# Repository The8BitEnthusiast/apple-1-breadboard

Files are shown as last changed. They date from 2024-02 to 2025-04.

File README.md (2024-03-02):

# Apple 1 Computer on Breadboard

Splash

This is an implementation of the Apple 1 computer on breadboard with the help of FPGA to support video display and PS/2 to ASCII keyboard conversion.

## Design Overview

This project builds upon Ben Eater's [6502 computer project](https://eater.net/6502). The base configuration of the WDC 65C02 microprocessor, 62256 RAM chip and 28C256 EEPROM is the same. Modifications made to the design to bring it into full compatibility with the Apple 1 are as follows:

- An FPGA is used to emulate the Apple 1 Video Terminal circuit and also to allow the use of a standard PS/2 keyboard by converting the PS/2 protocol to the ASCII signals expected by the Apple 1. The Video Terminal is the result of another project of mine, the details of which can be found [here](https://github.com/The8BitEnthusiast/apple-1-video-terminal-on-fpga).
- The 65C22 VIA IC is replaced with the 65C21 PIA, which is a drop-in replacement for the original PIA used on the Apple 1.
- Address decoding was adjusted to match the Apple 1's memory map. Worth noting is that the EEPROM is selected for the $F000-$FFFF address range, which was used to hold Wozmon, and the $C000-$CFFF range, used for Apple 1 Cassette Interface. RAM is selected for the bottom half of the memory space, and also for the $E000-$EFFF, which was used to load BASIC. This creates a range conflict with $6000-$6FFF, but for the purpose of this project, that was OK.

The top level schematic of this design is shown below. The KiCAD files are available in the schematics folder of this project.

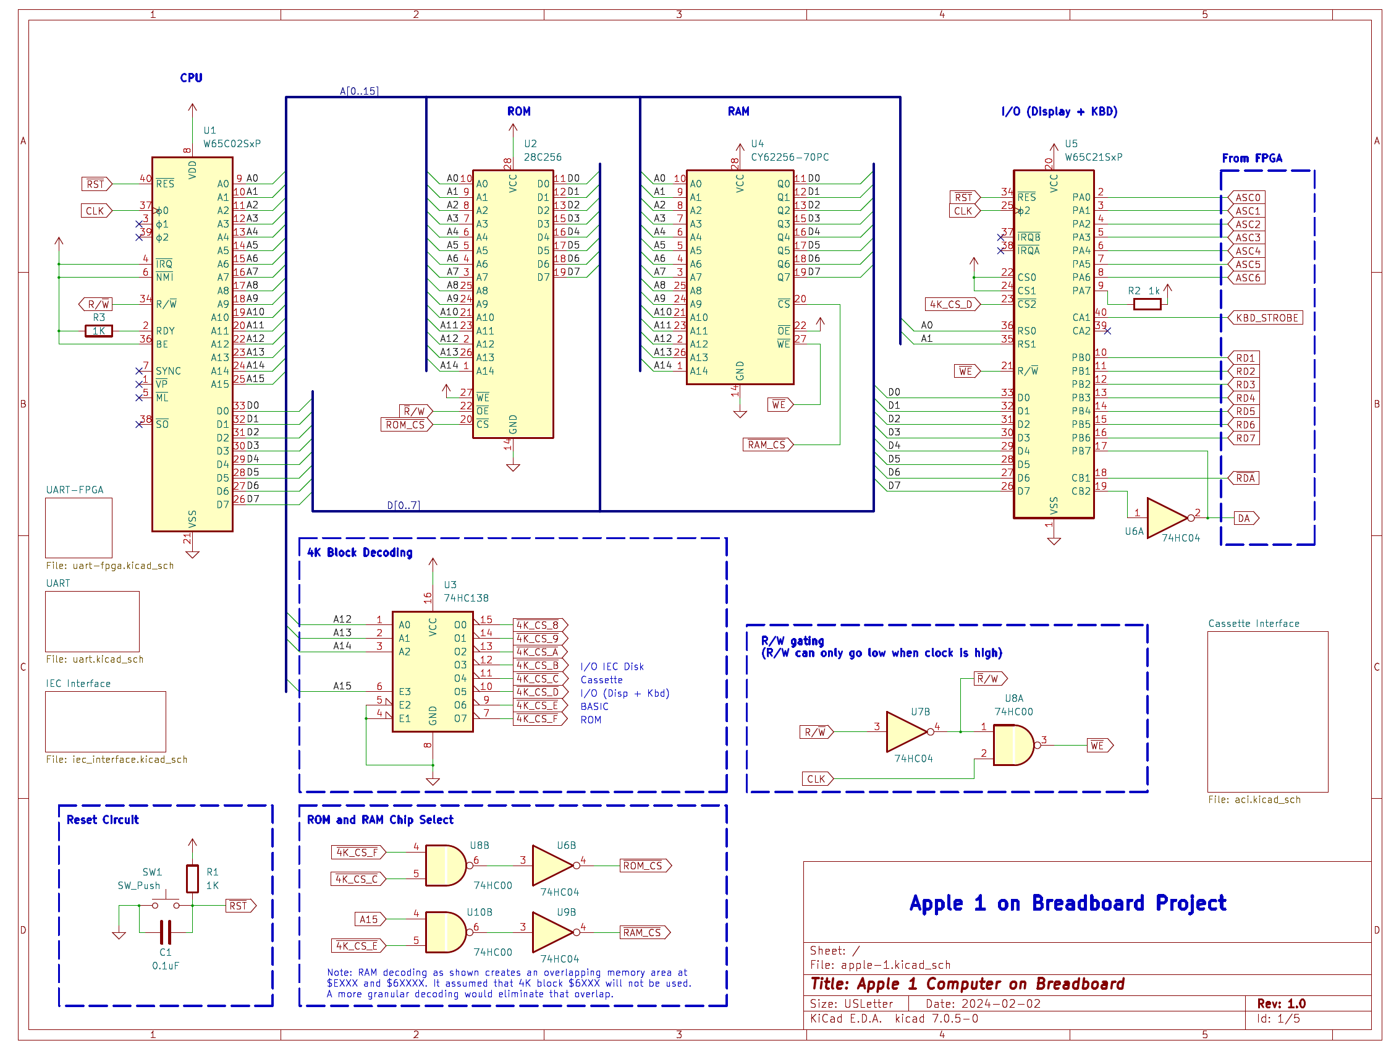
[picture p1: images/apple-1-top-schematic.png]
Top Schematic


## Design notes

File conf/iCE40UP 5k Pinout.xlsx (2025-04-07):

# Pin Out For iCE5UP5K (iCE40 UltraPlus - 5K)
# Revision 0.4 - Remove FWG49
# Revision 1.1 - Fix RGB pins, swapped C5 & A5 pins as well as 39 & 41
# Updated Jun 19, 2017
FNC | Pin Type | BANK | Differential Pair | UWG30 | SG48
IOB_0a | PIO | 2 |  | E5 | 46
IOB_2a | DPIO | 2 | TRUE_of_IOB_3b | D5 | 47
IOB_3b_G6 | DPIO/GBIN | 2 | COMP_of_IOB_2a | F5 | 44
IOB_4a | DPIO | 2 | TRUE_of_IOB_5b | - | 48
IOB_5b | DPIO | 2 | COMP_of_IOB_4a | - | 45
IOB_6a | PIO | 2 |  | - | 2
IOB_8a | DPIO | 2 | TRUE_of_IOB_9b | - | 4
IOB_9b | DPIO | 2 | COMP_of_IOB_8a | E4 | 3
IOB_10a | DPIO | 1 | TRUE_of_IOB_11b | C3 | -
IOB_11b_G5 | DPIO/GBIN | 1 | COMP_of_IOB_10a | F4 | -
creset_b | CONFIG | 1 |  | F3 | 8
IOB_12a_G4_CDONE | CONFIG/DPIO/GBIN | 1 | TRUE_of_IOB_13b | D3 | -
CDONE | CONFIG | 1 |  | - | 7
IOB_13b | DPIO | 1 | COMP_of_IOB_12a | E3 | 6
IOB_16a | PIO | 1 |  | - | 9
IOB_18a | PIO | 1 |  | - | 10
IOB_20a | PIO | 1 |  | - | 11
IOB_22a | DPIO | 1 | TRUE_of_IOB_23b | - | 12
IOB_23b | DPIO | 1 | COMP_of_IOB_22a | - | 21
IOB_24a | DPIO | 1 | TRUE_of_IOB_25b | B1 | 13
IOB_25b_G3 | DPIO/GBIN | 1 | COMP_of_IOB_24a | F2 | 20
IOB_29b | PIO | 1 |  | - | 19
IOB_31b | PIO | 1 |  | - | 18
IOB_32a_SPI_SO | DPIO/CONFIG_SPI | 1 |  | F1 | 14
IOB_33b_SPI_SI | DPIO/CONFIG_SPI | 1 |  | E1 | 17
IOB_34a_SPI_SCK | DPIO/CONFIG_SPI | 1 |  | D1 | 15
IOB_35b_SPI_SS | DPIO/CONFIG_SPI | 1 |  | C1 | 16
VCCPLL | VCCPLL |  |  | B2 | 29
IOT_36b | DPIO/I3C | 0 | COMP_of_IOT_37a | A1 | 25
IOT_37a | DPIO/I3C | 0 | TRUE_of_IOT_36b | A2 | 23
IOT_38b | DPIO | 0 | COMP_of_IOT_39a | - | 27
IOT_39a | DPIO | 0 | TRUE_of_IOT_38b | - | 26
IOT_41a | PIO | 0 |  | - | 28
IOT_42b | DPIO | 0 | COMP_of_IOT_43a | - | 31
IOT_43a | DPIO | 0 | TRUE_of_IOT_42b | - | 32
IOT_44b | DPIO | 0 | COMP_of_IOT_45a | - | 34
IOT_45a_G1 | DPIO/GBIN | 0 | TRUE_of_IOT_44b | - | 37
IOT_46b_G0 | DPIO/GBIN | 0 |  | B3 | 35
IOT_47a | PIO | 0 |  | A4 | -
IOT_48b | DPIO | 0 | COMP_of_IOT_49a | - | 36
IOT_49a | DPIO | 0 | TRUE_of_IOT_48b | - | 43
IOT_50b | DPIO | 0 | COMP_of_IOT_51a | - | 38
IOT_51a | DPIO | 0 | TRUE_of_IOT_50b | - | 42
RGB2 | LED | 0 |  | C5 | 41
RGB1 | LED | 0 |  | B5 | 40
RGB0 | LED | 0 |  | A5 | 39
GND | GND | GND |  | B4 | Paddle
GND | GND | GND |  | E2 | Paddle
GND | GND | GND |  | - | Paddle
VCC | VCC | VCC |  | C2 | 5
VCC | VCC | VCC |  | - | 30
VCCIO_0 | VCCIO | 0 |  | A3 | 33
SPI_Vccio1 | VCCIO | 1 |  | D2 | 22
VCCIO_2 | VCCIO | 2 |  | C4 | 1
VPP_2V5 | VPP | VPP |  | D4 | 24
*SG48 GND is connected to package paddle

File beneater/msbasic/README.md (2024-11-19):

# Microsoft BASIC for the Ben Eater 6502 project

This code was forked from [mist64/msbasic](https://github.com/mist64/msbasic) and I've added the code from my YouTube videos describing how to port MSBASIC to my 6502 project. The latest commit will match the code from the latest video.

But if you're following along with earlier videos, the "code" link below will take you to the code from that video:

| | Video | Code |
|---|---|---|
| Video thumbnail | [Running MSBASIC on my breadboard 6502 computer][video1] | [a15c8e0][commit1] |
| Video thumbnail | [How input buffering works][video2] | [54ef9ac][commit2] |
| Video thumbnail | [RS232 flow control][video3] | [c21542e][commit3] |
| Video thumbnail | [Hacking Microsoft BASIC][video4] | [master][commit4]  |

[thumbnail1]: https://i.ytimg.com/vi/XlbPnihCM0E/mqdefault.jpg
[video1]: https://youtu.be/XlbPnihCM0E
[commit1]: https://github.com/beneater/msbasic/tree/a15c8e0fdf620c800913cbb709df4042ab5c8dad

[thumbnail2]: https://i.ytimg.com/vi/mpIFag8zSWo/mqdefault.jpg
[video2]: https://youtu.be/mpIFag8zSWo
[commit2]: https://github.com/beneater/msbasic/tree/54ef9ac51f4134ac537c7011802a2f81112a242b

[thumbnail3]: https://i.ytimg.com/vi/LuKMVXWD7FY/mqdefault.jpg
[video3]: https://youtu.be/LuKMVXWD7FY
[commit3]: https://github.com/beneater/msbasic/tree/c21542e724b3da45ba3790405c2cf85e77bc1ad4

[thumbnail4]: https://i.ytimg.com/vi/gOwi2p1pzVM/mqdefault.jpg
[video4]: https://youtu.be/gOwi2p1pzVM
[commit4]: https://github.com/beneater/msbasic/tree/master

Below is the original README:

# Microsoft BASIC for 6502

This is a single integrated assembly source tree that can generate nine different versions of Microsoft BASIC for 6502.

By running ./make.sh, this will generate all versions and compare them to the original files byte by byte. The CC65 compiler suite is need to build this project.

These are the first ten (known) versions of Microsoft BASIC for 6502:

| Name | Release  | MS Version | ROM  | 9digit | INPUTBUFFER  | extensions  | .define |
| --- |:---:| --- |:----:|:---:|:---:|:---:| --- |
| Commodore BASIC 1 |  1977 | |  Y | Y | ZP | CBM | |
| OSI BASIC |  1977 | 1.0 REV 3.2  |  Y | N | ZP | - | CONFIG_10A |
| AppleSoft I |  1977 | 1.1 |  N | Y | $0200 | Apple | CONFIG_11  |
| KIM BASIC |  1977 | 1.1 |  N | Y | ZP | - | CONFIG_11A |
| AppleSoft II |  1978 | |  Y | Y | $0200 | Apple | CONFIG_2 |
| AIM-65 BASIC |  1978 | 1.1? |  Y | N | ZP | AIM | CONFIG_2A  |
| SYM-1 BASIC |  1978 | 1.1? |  Y | N | ZP | SYM | CONFIG_2A  |
| Commodore BASIC 2 |  1979 | |  Y | Y | $0200 | CBM | CONFIG_2A  |
| KBD BASIC |  1982 | |  Y | N | $0700 | KBD | CONFIG_2B  |
| MicroTAN |  1980 | |  Y | Y | ZP | - | CONFIG_2C  |

(Note that this assembly source cannot (yet) build AppleSoft II.)

This lists the versions in the order in which they were forked from the Microsoft source base. Commodore BASIC 1, as used on the original PET is the oldest known version of Microsoft BASIC for 6502. It contains some additions to Microsoft's version, like Commodore-style file I/O.

The CONFIG_n defines specify what Microsoft-version the OEM version is based on. If CONFIG_2B is defined, for example, CONFIG_2A, CONFIG_2, CONFIG_11A, CONFIG_11 and CONFIG_10A will be defined as well, and all bugfixes up to version 2B will be enabled.

The following symbols can be defined in addition:

| Configuration Symbol | Description
| --- | ---
| CONFIG_CBM1_PATCHES | jump out into CBM1's binary patches instead of doing the right thing inline
| CONFIG_CBM_ALL | add all Commodore-specific additions except file I/O
| CONFIG_DATAFLG | ?
| CONFIG_EASTER_EGG | include the CBM2 "WAIT 6502" easter egg
| CONFIG_FILE | support Commodore PRINT#, INPUT#, GET#, CMD
| CONFIG_IO_MSB | all I/O has bit #7 set
| CONFIG_MONCOUT_DESTROYS_Y | Y needs to be preserved when calling MONCOUT
| CONFIG_NO_CR | terminal doesn't need explicit CRs on line ends
| CONFIG_NO_LINE_EDITING | disable support for Microsoft-style "@", "_", BEL etc.
| CONFIG_NO_POKE | don't support PEEK, POKE and WAIT
| CONFIG_NO_READ_Y_IS_ZERO_HACK | don't do a very volatile trick that saves one byte
| CONFIG_NULL | support for the NULL statement
| CONFIG_PEEK_SAVE_LINNUM | preserve LINNUM on a PEEK
| CONFIG_PRINTNULLS | whether PRINTNULLS does anything
| CONFIG_PRINT_CR | print CR when line end reached
| CONFIG_RAM | optimizations for RAM version of BASIC, only use on 1.x
| CONFIG_ROR_WORKAROUND | use workaround for buggy 6502s from 1975/1976; not safe for CONFIG_SMALL!
| CONFIG_SAFE_NAMENOTFOUND | check both bytes of the caller's address in NAMENOTFOUND
| CONFIG_SCRTCH_ORDER | where in the init code to call SCRTCH
| CONFIG_SMALL | use 6 digit FP instead of 9 digit, use 2 character error messages, don't have GET
| CONFIG_SMALL_ERROR | use 2 character error messages

Changing symbol definitions can alter an existing base configuration, but it not guaranteed to assemble
or work correctly.

## More Information

More information on the differences of the respective versions can be found on this blog entry: [Create your own Version of Microsoft BASIC for 6502](http://www.pagetable.com/?p=46).

## License

2-clause BSD

## Credits

* Main work by Michael Steil <mist64@mac.com>.
* AIM-65 and SYM-1 by Martin Hoffmann-Vetter
* Function names and all uppercase comments taken from Bob Sander-Cederlof's excellent [AppleSoft II disassembly](http://www.txbobsc.com/scsc/scdocumentor/).
* [Applesoft lite](http://cowgod.org/replica1/applesoft/) by Tom Greene helped a lot, too.
* Thanks to Joe Zbicak for help with Intellision Keyboard BASIC
* This work is dedicated to the memory of my dear hacking pal Michael "acidity" Kollmann.

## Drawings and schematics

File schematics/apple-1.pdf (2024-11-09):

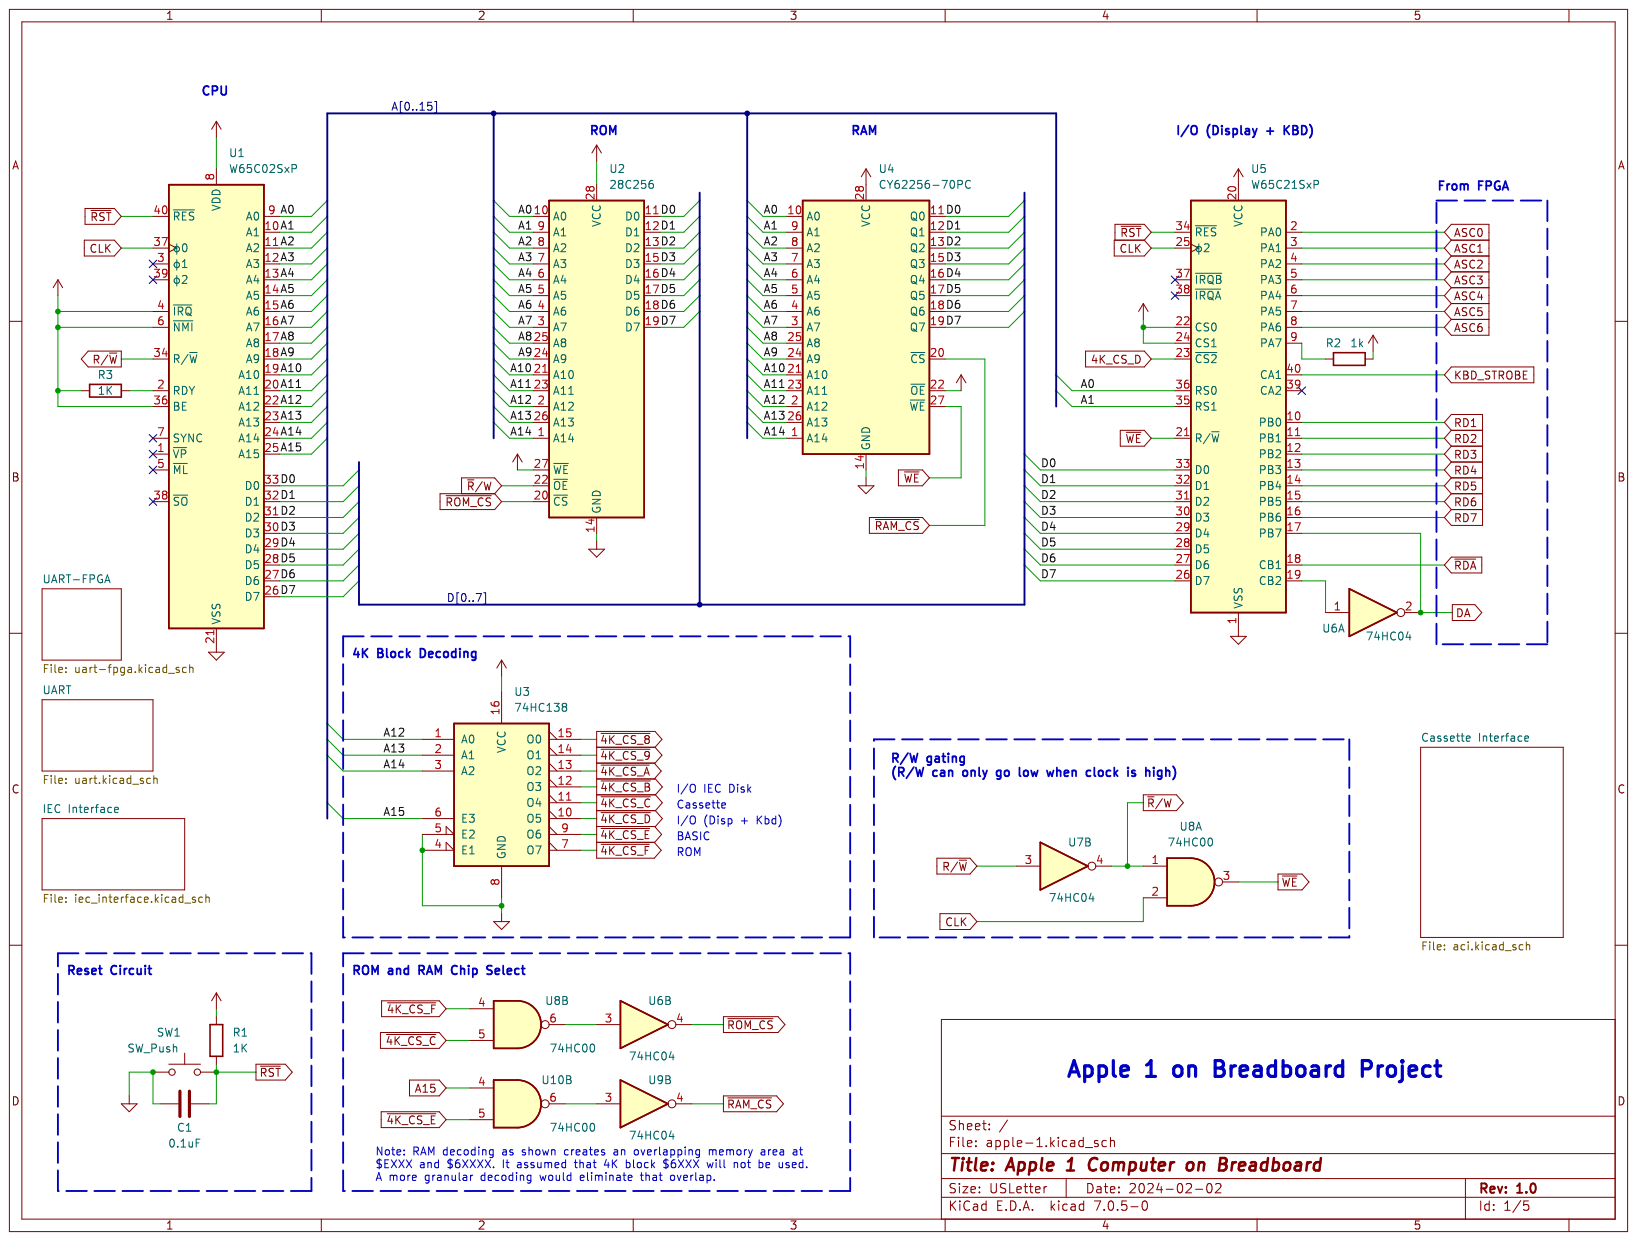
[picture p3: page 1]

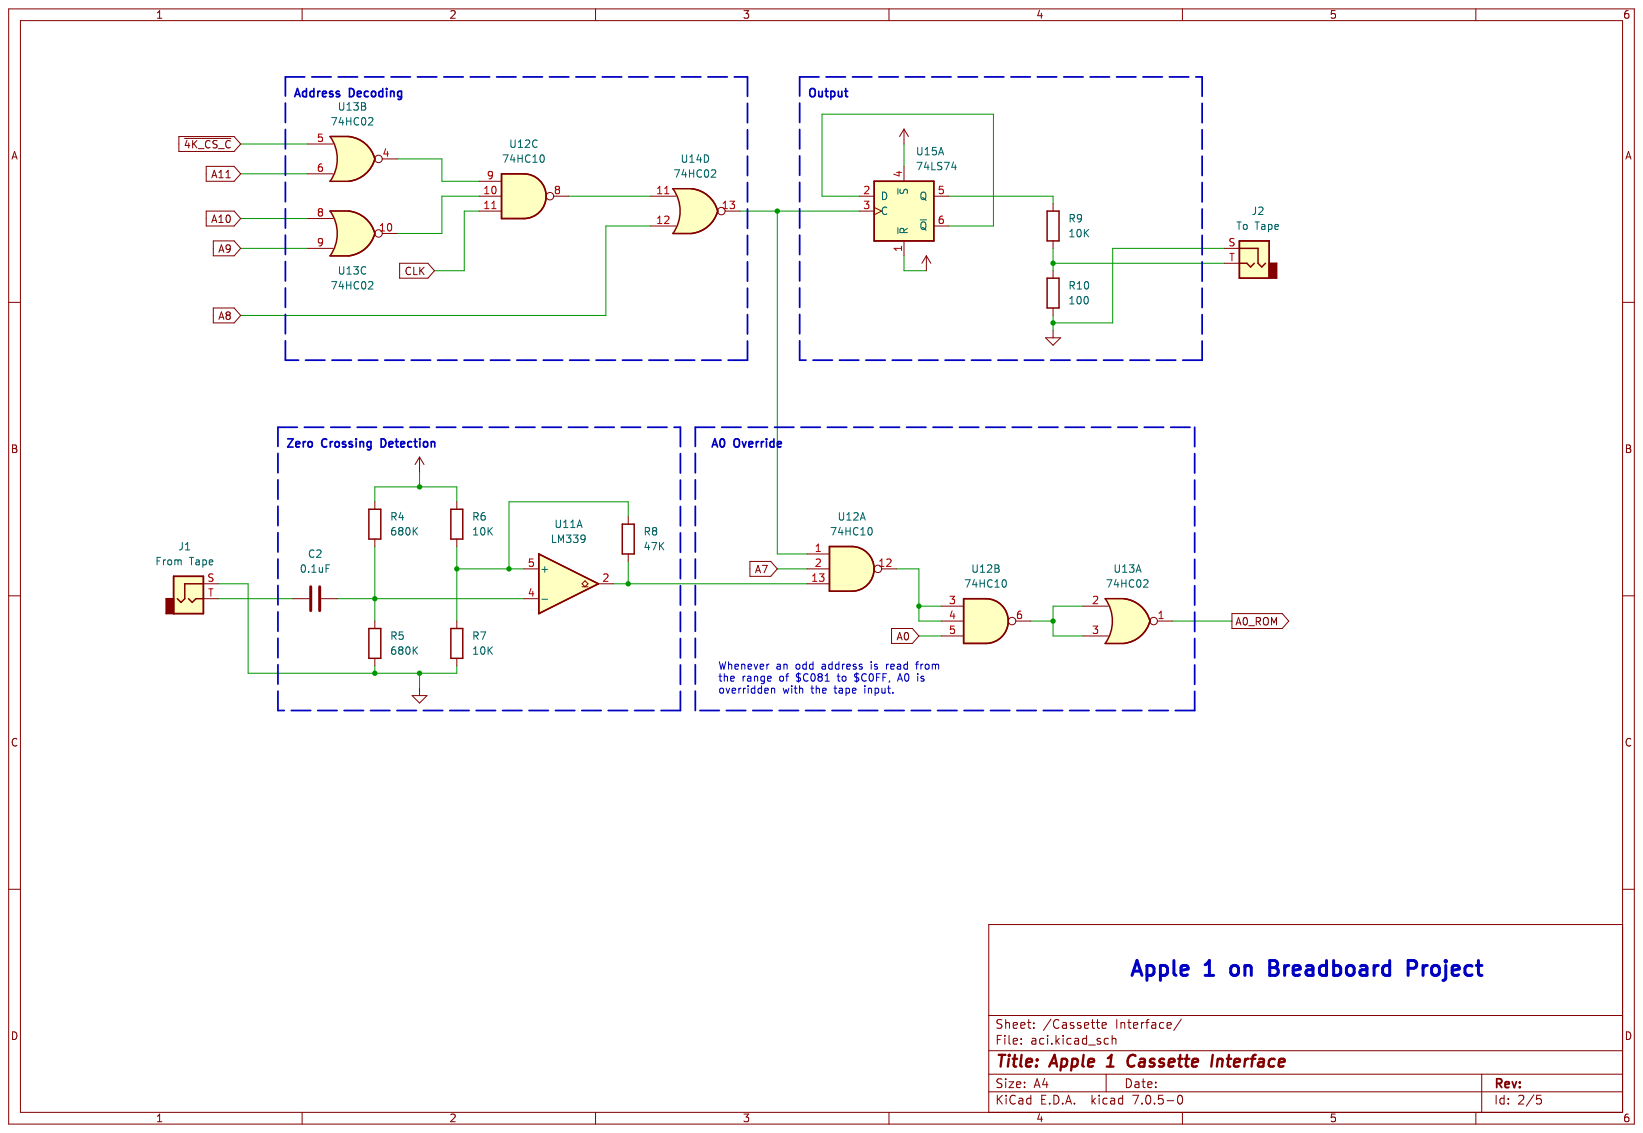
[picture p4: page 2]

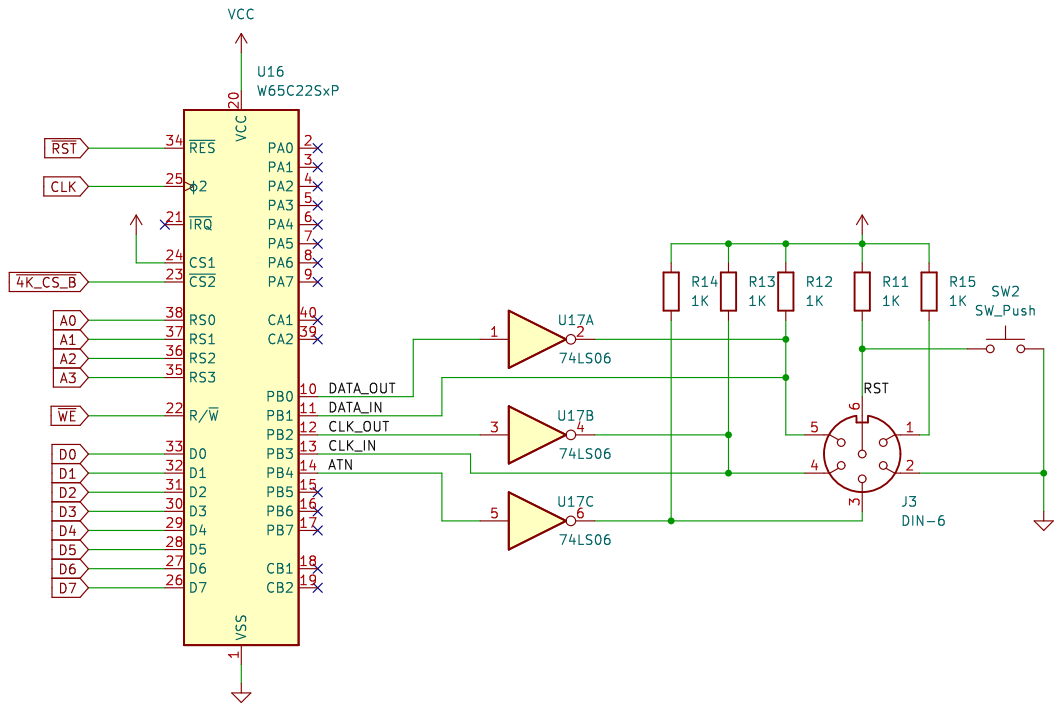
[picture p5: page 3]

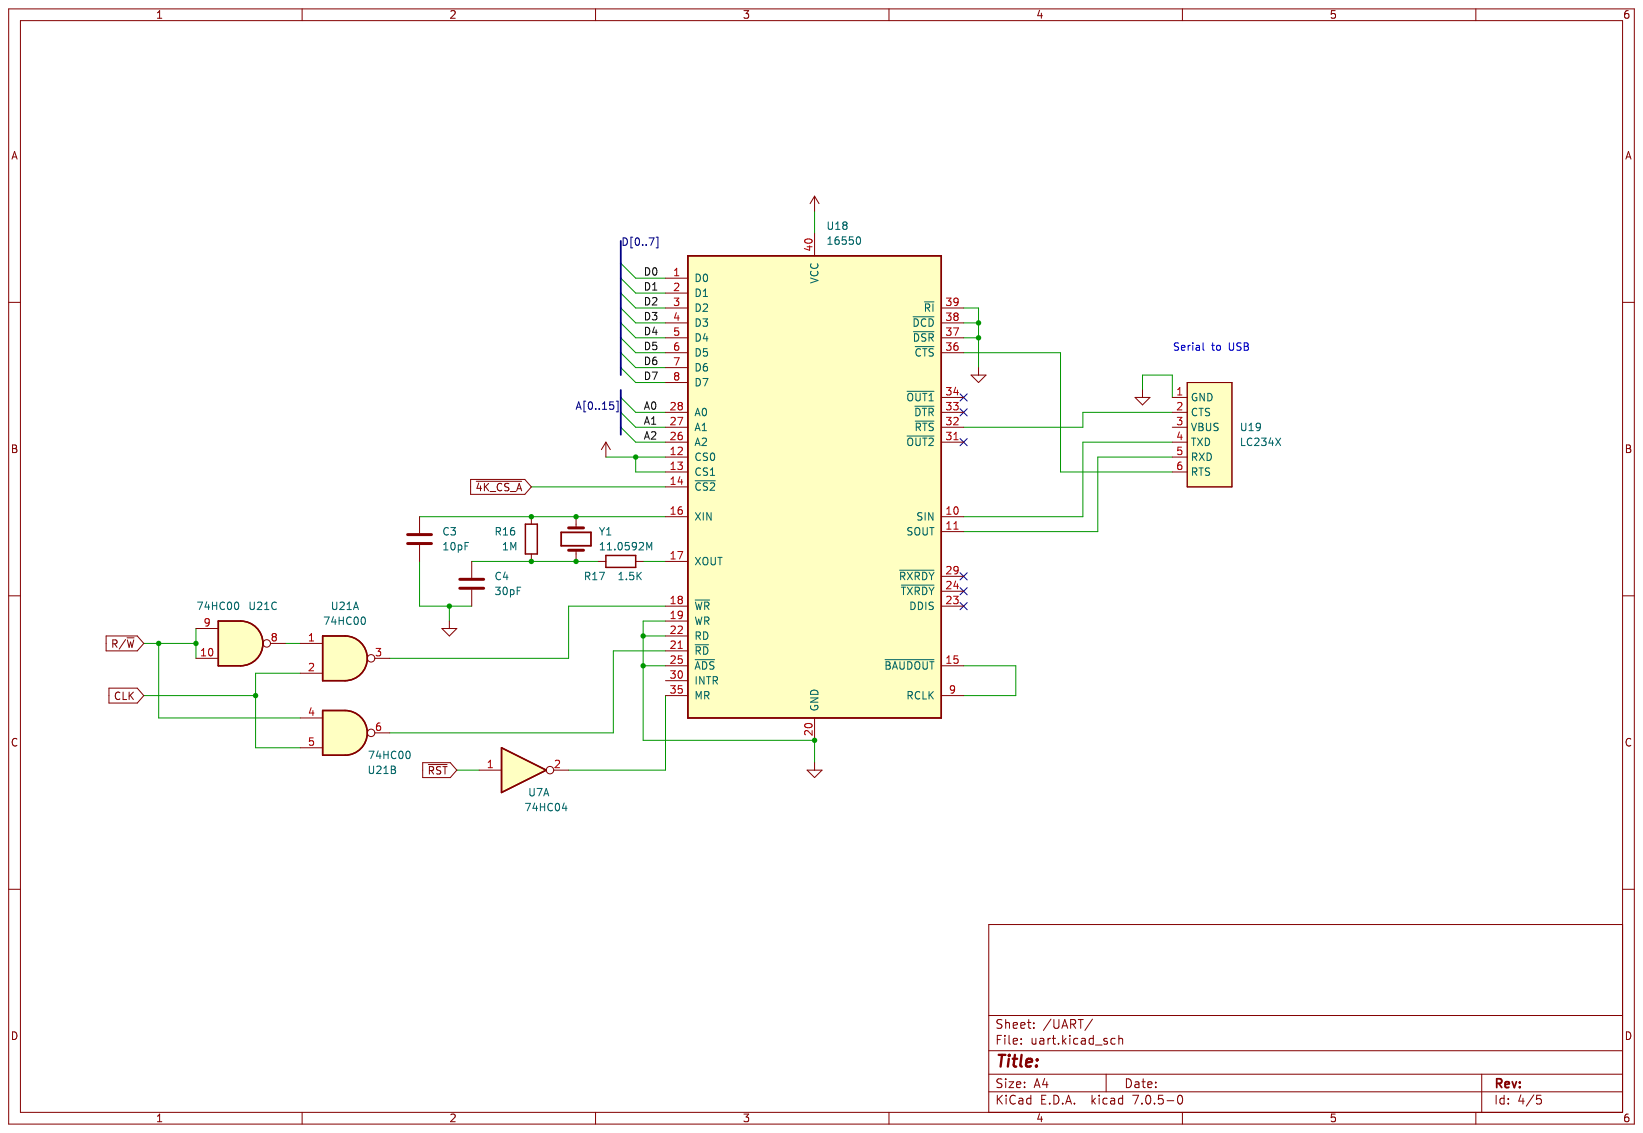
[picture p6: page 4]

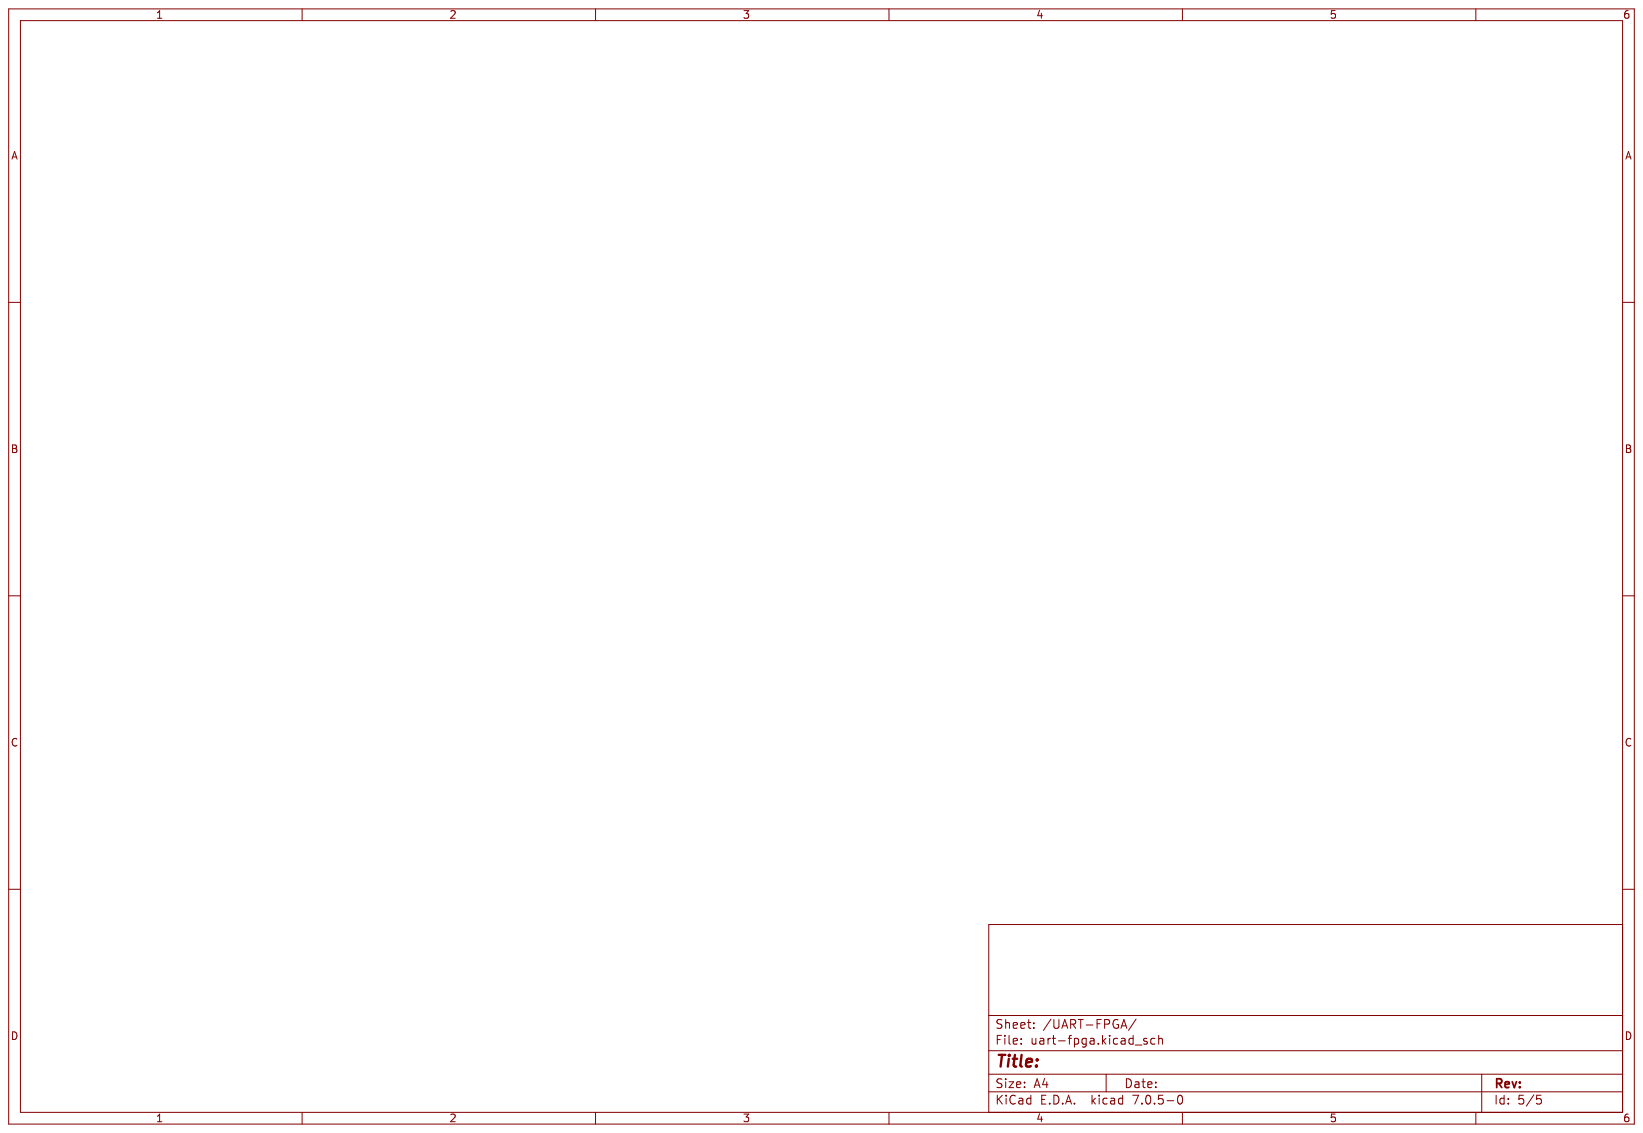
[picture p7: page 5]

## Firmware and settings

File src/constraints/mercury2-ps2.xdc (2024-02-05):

#      __  ____                 _   __                
#    /  |/  (_)_____________  / | / /___ _   ______ _
#   / /|_/ / / ___/ ___/ __ \/  |/ / __ \ | / / __ `/
#  / /  / / / /__/ /  / /_/ / /|  / /_/ / |/ / /_/ / 
# /_/  /_/_/\___/_/   \____/_/ |_/\____/|___/\__,_/  
#                                                  
# Mercury 2 User Constraints File
# Revision 0.B
# Copyright (c) 2019 MicroNova, LLC
# www.micro-nova.com

# general settings
set_property BITSTREAM.GENERAL.COMPRESS TRUE [current_design]

# on-board system oscillator
set_property -dict {PACKAGE_PIN N14 IOSTANDARD LVCMOS33} [get_ports {clk}]
set_property -dict {PACKAGE_PIN H16 IOSTANDARD LVCMOS33} [get_ports {clk_en}]

# on-board user LEDs
#set_property -dict {PACKAGE_PIN M1 IOSTANDARD LVCMOS33} [get_ports {led[0]}]
#set_property -dict {PACKAGE_PIN A14 IOSTANDARD LVCMOS33} [get_ports {led[1]}]
#set_property -dict {PACKAGE_PIN A13 IOSTANDARD LVCMOS33} [get_ports {led[2]}]

# FPGA: control signals
#set_property -dict {PACKAGE_PIN H10 IOSTANDARD LVCMOS33} [get_ports {fpga_done}]
#set_property -dict {PACKAGE_PIN L9 IOSTANDARD LVCMOS33} [get_ports {fpga_prog}]


# FPGA Direct I/O
#set_property -dict {PACKAGE_PIN C12 IOSTANDARD LVCMOS33} [get_ports {dio[0]}]
#set_property -dict {PACKAGE_PIN C11 IOSTANDARD LVCMOS33} [get_ports {dio[1]}]
#set_property -dict {PACKAGE_PIN D9 IOSTANDARD LVCMOS33} [get_ports {dio[2]}]
#set_property -dict {PACKAGE_PIN A9 IOSTANDARD LVCMOS33} [get_ports {dio[3]}]
#set_property -dict {PACKAGE_PIN A8 IOSTANDARD LVCMOS33} [get_ports {dio[4]}]
#set_property -dict {PACKAGE_PIN A10 IOSTANDARD LVCMOS33} [get_ports {dio[5]}]
#set_property -dict {PACKAGE_PIN B9 IOSTANDARD LVCMOS33} [get_ports {dio[6]}]
#set_property -dict {PACKAGE_PIN B6 IOSTANDARD LVCMOS33} [get_ports {dio[7]}]
#set_property -dict {PACKAGE_PIN B5 IOSTANDARD LVCMOS33} [get_ports {dio[8]}]
#set_property -dict {PACKAGE_PIN E12 IOSTANDARD LVCMOS33} [get_ports {dio[9]}]

# 5V tolerant level shifted I/O
#set_property -dict {PACKAGE_PIN G1 IOSTANDARD LVCMOS33} [get_ports {io[0]}]
#set_property -dict {PACKAGE_PIN G2 IOSTANDARD LVCMOS33} [get_ports {io[1]}]
#set_property -dict {PACKAGE_PIN F2 IOSTANDARD LVCMOS33} [get_ports {io[2]}]
#set_property -dict {PACKAGE_PIN E1 IOSTANDARD LVCMOS33} [get_ports {io[3]}]
#set_property -dict {PACKAGE_PIN E2 IOSTANDARD LVCMOS33} [get_ports {io[4]}]
#set_property -dict {PACKAGE_PIN C2 IOSTANDARD LVCMOS33} [get_ports {io[5]}]
#set_property -dict {PACKAGE_PIN B2 IOSTANDARD LVCMOS33} [get_ports {io[6]}]
#set_property -dict {PACKAGE_PIN B1 IOSTANDARD LVCMOS33} [get_ports {io[7]}]
#set_property -dict {PACKAGE_PIN A2 IOSTANDARD LVCMOS33} [get_ports {io[8]}]
#set_property -dict {PACKAGE_PIN H2 IOSTANDARD LVCMOS33} [get_ports {io[9]}]
set_property -dict {PACKAGE_PIN B10 IOSTANDARD LVCMOS33} [get_ports {ps2_data}];  # io[10]
set_property -dict {PACKAGE_PIN C8 IOSTANDARD LVCMOS33} [get_ports {ps2_clk}];    # io[11]
#set_property -dict {PACKAGE_PIN C9 IOSTANDARD LVCMOS33} [get_ports {io[12]}];
#set_property -dict {PACKAGE_PIN T13 IOSTANDARD LVCMOS33} [get_ports {io[13]}]
#set_property -dict {PACKAGE_PIN R12 IOSTANDARD LVCMOS33} [get_ports {io[14]}]
#set_property -dict {PACKAGE_PIN P11 IOSTANDARD LVCMOS33} [get_ports {io[15]}]
#set_property -dict {PACKAGE_PIN T2 IOSTANDARD LVCMOS33} [get_ports {io[16]}]
#set_property -dict {PACKAGE_PIN T4 IOSTANDARD LVCMOS33} [get_ports {io[17]}]
#set_property -dict {PACKAGE_PIN T5 IOSTANDARD LVCMOS33} [get_ports {io[18]}]
#set_property -dict {PACKAGE_PIN T7 IOSTANDARD LVCMOS33} [get_ports {io[19]}]
#set_property -dict {PACKAGE_PIN K5 IOSTANDARD LVCMOS33} [get_ports {io[20]}]
#set_property -dict {PACKAGE_PIN A3 IOSTANDARD LVCMOS33} [get_ports {io[21]}]
#set_property -dict {PACKAGE_PIN C6 IOSTANDARD LVCMOS33} [get_ports {io[22]}]
#set_property -dict {PACKAGE_PIN D4 IOSTANDARD LVCMOS33} [get_ports {io[23]}]
#set_property -dict {PACKAGE_PIN F5 IOSTANDARD LVCMOS33} [get_ports {io[24]}]
#set_property -dict {PACKAGE_PIN D8 IOSTANDARD LVCMOS33} [get_ports {io[25]}]
#set_property -dict {PACKAGE_PIN P1 IOSTANDARD LVCMOS33} [get_ports {io[26]}]
#set_property -dict {PACKAGE_PIN C7 IOSTANDARD LVCMOS33} [get_ports {io[27]}]
#set_property -dict {PACKAGE_PIN M2 IOSTANDARD LVCMOS33} [get_ports {io[28]}]
set_property -dict {PACKAGE_PIN N1 IOSTANDARD LVCMOS33} [get_ports {ascii_code[6]}];      # io[29]
set_property -dict {PACKAGE_PIN C1 IOSTANDARD LVCMOS33} [get_ports {ascii_code[5]}];      # io[30]
set_property -dict {PACKAGE_PIN D1 IOSTANDARD LVCMOS33} [get_ports {ascii_code[4]}];      # io[31]
set_property -dict {PACKAGE_PIN L2 IOSTANDARD LVCMOS33} [get_ports {ascii_code[3]}];      # io[32]
set_property -dict {PACKAGE_PIN G5 IOSTANDARD LVCMOS33} [get_ports {ascii_code[2]}];      # io[33]
set_property -dict {PACKAGE_PIN H5 IOSTANDARD LVCMOS33} [get_ports {ascii_code[1]}];      # io[34]
set_property -dict {PACKAGE_PIN H1 IOSTANDARD LVCMOS33} [get_ports {ascii_code[0]}];      # io[35]
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

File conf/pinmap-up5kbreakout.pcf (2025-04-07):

# Pin configuration file for UP5K Breakout board
# General syntax: set_io [-nowarn] [-pullup yes|no] [-pullup_resistor 3P3K|6P8K|10K|100K] port pin

set_io      clk             35  # 12 Mhz clock

# HEADER A
# set_io      led_red         41  
# set_io      led_green       40
set_io      heartbeat       39   # LED blue

# HEADER C
set_io -pullup yes     rd[7]           4    # iob_8a
set_io -pullup yes     rd[6]           3    # iob_9b
set_io -pullup yes     rd[5]           48   # iob_4a
set_io -pullup yes     rd[4]           45   # iob_5b
set_io -pullup yes     rd[3]           47   # iob_2a     
set_io -pullup yes     rd[2]           44   # iob_3b_g6  
set_io -pullup yes     rd[1]           46   # iob_0a     
# set_io      iob_6a          2    # iob_6a     
set_io      da              12   # iob_22a    
set_io      rda             21   # iob_23b    
set_io      clr_btn         13   # iob_24a    
set_io      vid1            20   # iob_25b_g3 - goes to 680 ohm resistor
set_io      vid2            19   # iob_29b    - goes to 330 ohm resistor
# set_io      iob_31b         18   # iob_31b    
# set_io      iob_20a         11   # iob_20a    
# set_io      iob_18a         10   # iob_18a    
# set_io      iob_16a         9    # iob_16a    
set_io      debug         6    # iob_13b    

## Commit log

2024-02-05 updated schematics
    [apple-1.kicad_sch]
2024-02-25 added first batch of ACI files
    [aci.kicad_sch, aci_wozmon.cfg, apple-1.kicad_sch]
2024-02-25 schematics updates
    [aci.kicad_sch]
2024-02-25 minor correction to schematics
    [aci.kicad_sch]
2024-02-27 updates to schematics and 6502 source for ACI
    [aci.kicad_sch, aci_wozmon.cfg, apple-1.kicad_sch]
2024-11-09 added UART to design
    [aci.kicad_sch, apple-1.kicad_sch, iec_interface.kicad_sch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]
2024-11-09 added UART to design schematics
2024-11-19 apple II monitor
    [aci_woz_apl2mon_serial.cfg, aci_wozmon_serial.cfg, aim65.cfg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]
2025-04-07 added ice40 support
    [apple-1.kicad_sch, iCE40UP 5k Pinout.xlsx, uart.kicad_sch]
